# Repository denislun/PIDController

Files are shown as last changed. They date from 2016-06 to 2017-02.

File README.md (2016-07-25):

# Thermocouple PID Controller

A PID controller based on an Arduino using a MAX6675 Thermocouple module.

Current temperature and setpoint will be shown on the LCD display, along with current output state.

## Parts List

* Atmel Atmega328p MCU
* PCD8544 LCD Screen
* MAX6675 Thermocouple interface chip
* Rotary Encoder
* Relay to drive the output

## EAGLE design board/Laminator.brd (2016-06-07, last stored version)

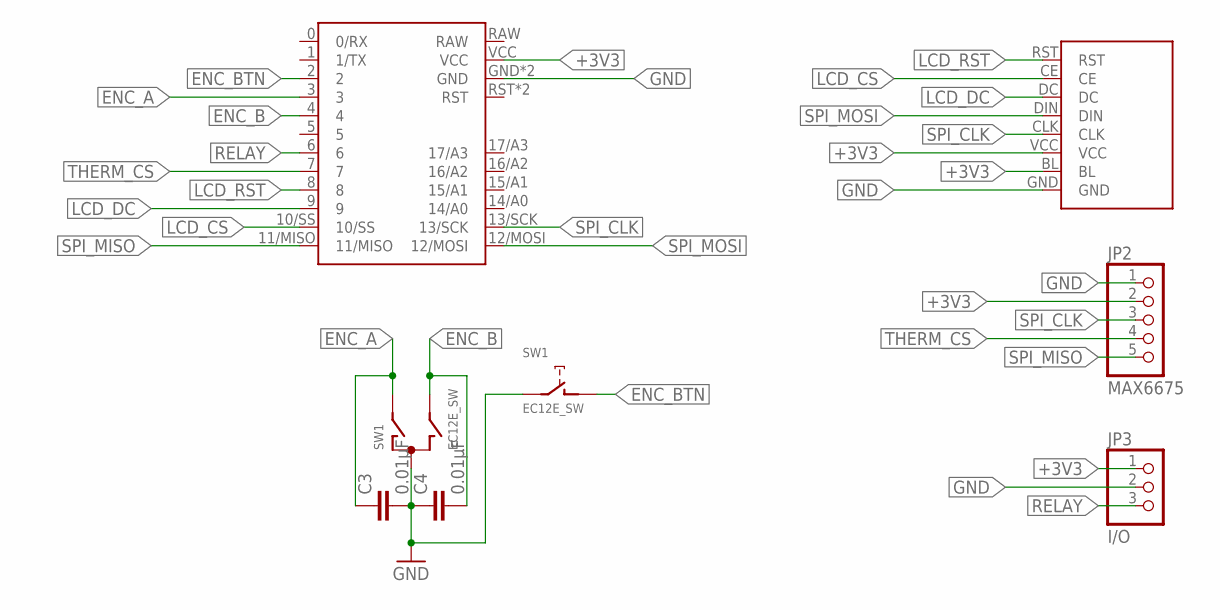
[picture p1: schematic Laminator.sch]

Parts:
ARDUINO: ARDUINO_PRO_MINI_DIL; ARDUINO_PRO_MINI_B
C3, C4: 0.01µF; C025-025X050
JP2: MAX6675; 1X05
JP3: I/O; 1X03
SW1: EC12E_SW; ALPS_EC12E_SW
U$1: NOKIA_5110

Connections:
+3V3: ARDUINO.VCC, JP2.2, JP3.1, U$1.BL, U$1.VCC
ENC_A: ARDUINO.3, C3.1, SW1.A
ENC_B: ARDUINO.4, C4.2, SW1.B
ENC_BTN: ARDUINO.2, SW1.D (1)
GND: ARDUINO.GND, ARDUINO.GND@2 (GND), C3.2, C4.1, JP2.1, JP3.2, SW1.C, SW1.E (2), U$1.GND
LCD_CS: ARDUINO.10/SS, U$1.CE
LCD_DC: ARDUINO.9, U$1.DC
LCD_RST: ARDUINO.8, U$1.RST
RELAY: ARDUINO.6, JP3.3
SPI_CLK: ARDUINO.13/SCK, JP2.3, U$1.CLK
SPI_MISO: ARDUINO.11/MISO, JP2.5
SPI_MOSI: ARDUINO.12/MOSI, U$1.DIN
THERM_CS: ARDUINO.7, JP2.4

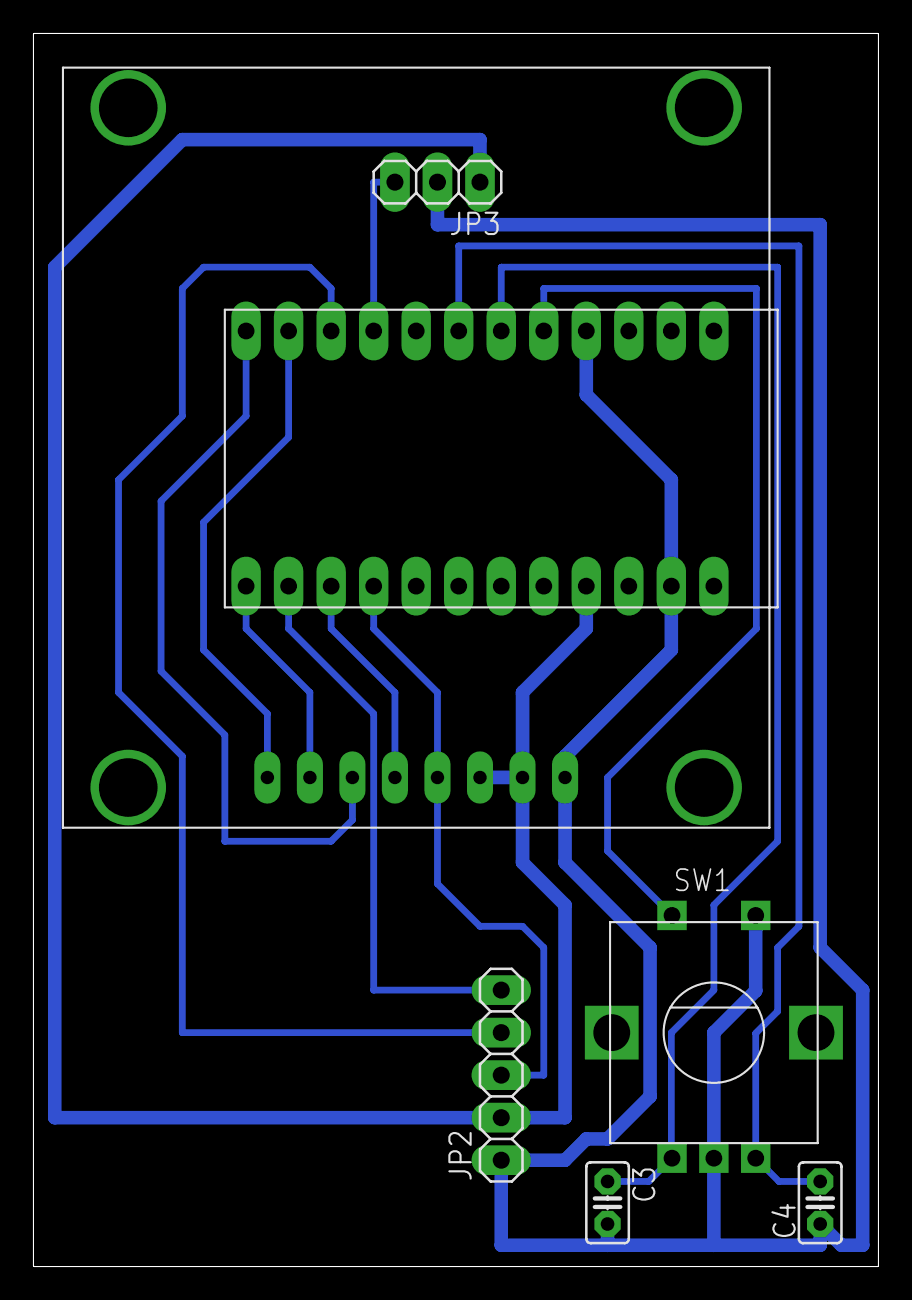
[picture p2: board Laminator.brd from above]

Board: 2 copper layers, 50.5 x 73.7 mm, 7 parts (0 on the bottom side), 13 nets.

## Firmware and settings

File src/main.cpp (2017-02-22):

#include <Arduino.h>
#include <SPI.h>

#include "temperature.h"
#include "pid.h"
#include "relay.h"
#include "display.h"
#include "encoder.h"

void setup() {
  SPI.begin();
  setupDisplay();
  setupRelay();
  setupEncoder();
  setupThermocouple();
  setupPID();
}

void loop() {
  loopEncoder();
  loopThermocouple();
  loopPID();
  loopDisplay();
}

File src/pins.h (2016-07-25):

#ifndef _PINS_H
#define _PINS_H

#define SPI_CLK 13
#define SPI_MISO 12
#define SPI_MOSI 11

#define THERMOCOUPLE_CS 8

#define LCD_DC 14
#define LCD_CS 15
#define LCD_RST 16

#define ENCODER_A 4
#define ENCODER_B 3
#define ENCODER_BTN 2

#define RELAY 6

#endif

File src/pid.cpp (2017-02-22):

#include <Arduino.h>
#include <PID_v1.h>
#include <PID_AutoTune_v0.h>
#include "pid.h"
#include "temperature.h"
#include "encoder.h"
#include "relay.h"
#include "settings.h"
#include "display.h"

#define OFF    "OFF    "
#define ON     "RUNNING"
#define TUNING "TUNING "

double setPoint = 100;
double output;
double Kp=2, Ki=5, Kd=1;
unsigned int windowSize = 5000;
unsigned long windowStartTime = millis();
PID pid(&currentTemperature, &output, &setPoint, Kp, Ki, Kd, DIRECT);

PID_ATune autoTuner(&currentTemperature, &output);
double autoTuneStep = 500;
double autoTuneNoise = 1;
int autoTuneLookback = 20;
bool autoTuning = false;

void pidStartAutoTune() {
  autoTuner.SetNoiseBand(autoTuneNoise);
  autoTuner.SetOutputStep(autoTuneStep);
  autoTuner.SetLookbackSec(autoTuneLookback);
  autoTuning = true;
}

void pidFinishAutotune() {
  autoTuning = false;

  // Extract the auto-tune calculated parameters
  Kp = autoTuner.GetKp();
  Ki = autoTuner.GetKi();
  Kd = autoTuner.GetKd();

  saveKp(Kp);
  saveKi(Ki);
  saveKd(Kd);

  pid.SetTunings(Kp, Ki, Kd);
  pid.SetMode(MANUAL);
}

void setupPID() {
  Kp = loadKp();
  Ki = loadKi();
  Kd = loadKd();

  pid.SetOutputLimits(0, windowSize);
  pid.SetMode(MANUAL);
  pid.SetControllerDirection(DIRECT);

  displayStatus(OFF);
  displayTargetTemperature(setPoint);
}

void loopPID() {
  if(encoderButtonWasPressed) {
    if(pid.GetMode() == AUTOMATIC) {
      // Turn off
      pid.SetMode(MANUAL);
      setRelay(false);
      displayStatus(OFF);
    }
    else {
      // Turn on
      pid.SetMode(AUTOMATIC);
      displayStatus(ON);
    }
  } else if(encoderButtonWasHeld) {
    // Autotune
    pidStartAutoTune();
    displayStatus(TUNING);
  }

  if(autoTuning) {
    if(autoTuner.Runtime()) {
      pidFinishAutotune();
      displayStatus(OFF);
    }
    else {
      setRelay(output < (millis() - windowStartTime));
    }
  }
  else if(pid.GetMode() == AUTOMATIC) {
    pid.Compute();
    setRelay(output < (millis() - windowStartTime));
  }

  encoderButtonWasHeld = false;
  encoderButtonWasPressed = false;
}

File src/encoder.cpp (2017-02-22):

#include <Arduino.h>
#include "encoder.h"
#include "pins.h"
#include "pid.h"
#include "display.h"

#define HOLD_TIME 5000

#define TEMP_MIN 0
#define TEMP_MAX 250

volatile int movement = 0;
volatile bool encoderButtonWasPressed = false;
volatile bool encoderButtonWasHeld = false;
volatile unsigned long encoderButtonPressedAt;

void encoderInterrupt() {
  if(digitalRead(ENCODER_A) && digitalRead(ENCODER_B)) // b is leading
    movement += 1;
  else // a is leading
    movement -= 1;
}

void encoderButtonInterrupt() {
  if(digitalRead(ENCODER_BTN)) {
    if(millis() - encoderButtonPressedAt > HOLD_TIME)
      encoderButtonWasHeld = true;
    else
      encoderButtonWasPressed = true;
  }
  else
    encoderButtonPressedAt = millis();
}

double limitValue(double value, double min, double max) {
  if(value < min)
    return min;
  else if(value > max)
    return max;
  else
    return value;
}

void setupEncoder() {
  pinMode(ENCODER_BTN, INPUT_PULLUP);
  pinMode(ENCODER_A, INPUT_PULLUP);
  pinMode(ENCODER_B, INPUT_PULLUP);

  attachInterrupt(digitalPinToInterrupt(ENCODER_B), encoderInterrupt, RISING);
  attachInterrupt(digitalPinToInterrupt(ENCODER_BTN), encoderButtonInterrupt, CHANGE);
}

void loopEncoder() {
  if(movement != 0) {
    setPoint = limitValue(setPoint + movement, TEMP_MIN, TEMP_MAX);
    movement = 0;
    displayTargetTemperature(setPoint);
  }
}

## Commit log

2016-06-07 Update for prototype board
2016-06-07 Add board and schematic
    [Laminator.brd, Laminator.sch]
2016-06-07 Add readme and schematic png
2016-07-25 Better use of hardware SPI
    * Remove bitbanging MAX6675 library
    * Modify Adafruit_PCD8544 to use SPI transactions
    * Add Thermocouple library & use SPI transactions
    [Laminator.brd, Laminator.sch]
